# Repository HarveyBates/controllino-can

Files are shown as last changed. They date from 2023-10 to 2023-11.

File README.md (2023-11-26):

# Controllino-CAN
Small PCB that fits onto the header of a [Controllino-MEGA](https://www.controllino.com/product/controllino-mega/) allowing it to interface with CAN devices through SPI. Does not take up any output/input pins!

<p float="left" align="center">
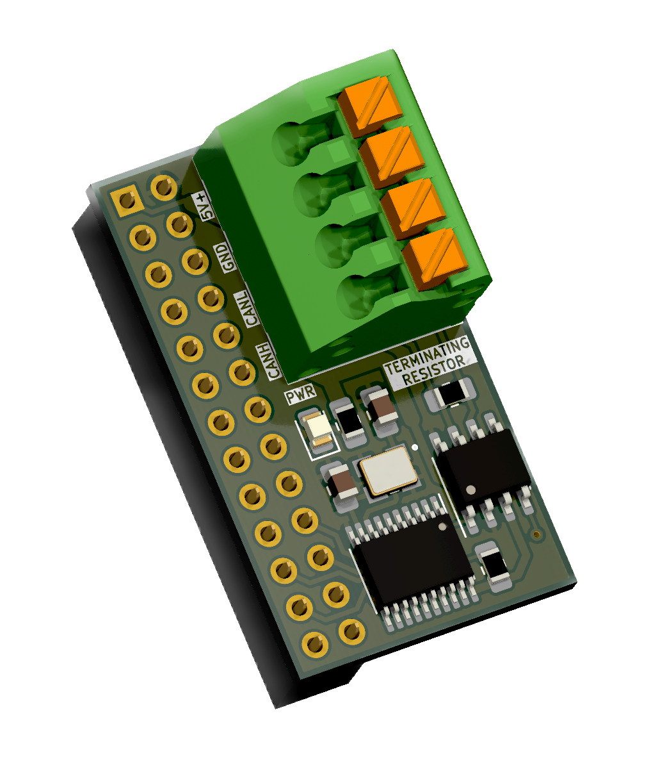
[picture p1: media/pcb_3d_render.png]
   
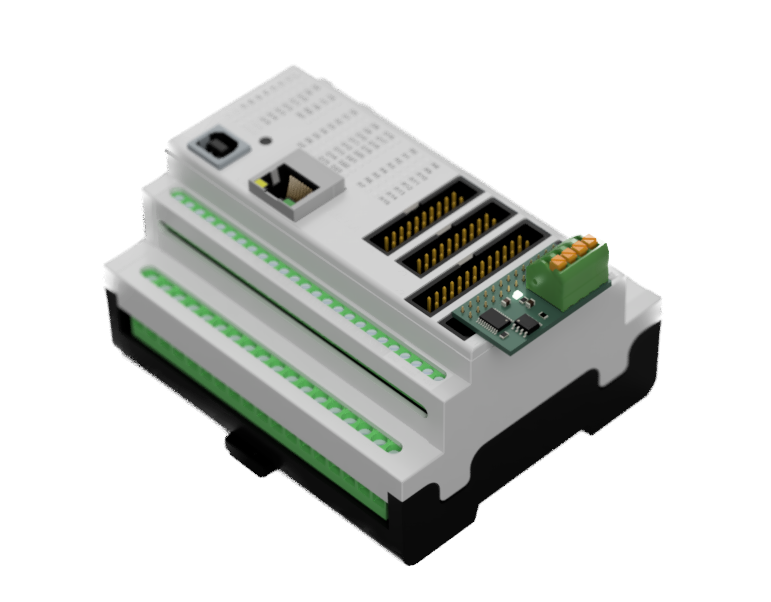
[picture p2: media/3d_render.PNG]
  
</p>

## Example Code
Utilises the [MCP2515 arduino library](https://github.com/autowp/arduino-mcp2515). See futher information in the [examples folder](https://github.com/HarveyBates/controllino-can/tree/main/examples).

```cpp
#include <Controllino.h>
#include "mcp2515.h"

#define BIT_RATE CAN_500KBPS
#define NODE_ID 0x0A // Node-ID = 10
#define FUNCTION_CODE 0x180 // CANopen PDO1_TX

// Setup MCP2515 lib with SPI chip-select pin
MCP2515 can(CONTROLLINO_PIN_HEADER_SS);

void setup() {
  Serial.begin(115200);
  Controllino_RTC_init();
  can.reset();
  can.setBitrate(BIT_RATE, MCP_8MHZ);
  can.setNormalMode();
}

void loop() {
  can_frame frame{};
  frame.can_dlc = 8;
  frame.can_id = FUNCTION_CODE | NODE_ID;
  if (can.sendMessage(&frame) == MCP2515::ERROR_OK) {
    Serial.println("TX");
  } else {
    Serial.println("ERR");
  }
  delay(5000);
}
```

## BOM
The bill-of-materials can be found [here](https://github.com/HarveyBates/controllino-can/blob/main/bom/controllino-can-digikey.csv). **The componets only cost $12 AUD ($8 USD).**

## PCB ordering
Compress the [gerber folder](https://github.com/HarveyBates/controllino-can/tree/main/electronics/gerber) and upload to your PCB manufactuer of choice (e.g. [jlcpcb]([https://jlcpcb.com/](https://cart.jlcpcb.com/quote/)https://cart.jlcpcb.com/quote/) or [PCBway](https://www.pcbway.com/) etc.). As the components are SMD (0805 smallest size) get a stencil (top-side of PCB only) to make assembly easier. **PCB plus stencil is roughly $15 AUD ($10 USD).**

## Licence
Controllino-CAN is licenced under the GNU General Public Licence v3.0 as outlined in the [LICENCE](https://github.com/HarveyBates/controllino-can/blob/main/LICENSE).

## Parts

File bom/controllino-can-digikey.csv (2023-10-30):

Index | Manufacturer Part Number | Manufacturer Name | Description | Availability | Stock Status | Attrition % | Requested Quantity 1 | Pack Quantity 1 | Pack Type 1 | Digi-Key Part Number 1 | Unit Price 1 | Extended Price 1 | Minimum Order Quantity 1 | Customer Reference | Requested Part Number | Lead Weeks | Datasheet | Reference Designator | Part Status
1 | MCP2515T-I/ST | Microchip Technology | IC CAN CONTROLLER W/SPI 20TSSOP | 12,353 | In Stock |  | 1 | 1 | Cut Tape (CT) | MCP2515T-I/STCT-ND | 4.36000 | $4.36 | 1 |  | MCP2515T-I/STCT-ND | 4 | https://ww1.microchip.com/downloads/en/DeviceDoc/MCP2515-Stand-Alone-CAN-Controller-with-SPI-20001801J.pdf |  | Active
2 | C0805C220J5GAC7210 | KEMET | CAP CER 22PF 50V C0G/NP0 0805 | 49,151 | In Stock |  | 2 | 2 | Cut Tape (CT) | 399-C0805C220J5GAC7210CT-ND | 0.16000 | $0.32 | 1 |  | 399-C0805C220J5GAC7210CT-ND | 27 | https://connect.kemet.com:7667/gateway/IntelliData-ComponentDocumentation/1.0/download/datasheet/C0805C220J5GAC7210 |  | Active
3 | LTST-C171GKT | Lite-On Inc. | LED GREEN CLEAR CHIP SMD | 291,266 | In Stock |  | 1 | 1 | Cut Tape (CT) | 160-1423-1-ND | 0.41000 | $0.41 | 1 |  | 160-1423-1-ND | 18 | https://mm.digikey.com/Volume0/opasdata/d220001/medias/docus/1134/LTST-C171GKT.pdf |  | Active
4 | TBL002A-350-04GR-2OR | CUI Devices | TERMINAL BLOCK, SCREWLESS, 3.50, | 128 | In Stock |  | 1 | 1 | Tray | 102-6381-ND | 1.53000 | $1.53 | 1 |  | 102-6381-ND | 11 | https://www.cuidevices.com/product/resource/tbl002a-350.pdf |  | Active
5 | SFH11-PBPC-D13-ST-BK | Sullins Connector Solutions | CONN HDR 26POS 0.1 GOLD PCB | 9,218 | In Stock |  | 1 | 1 | Tray | S9198-ND | 2.27000 | $2.27 | 1 |  | S9198-ND | 11 | https://s3.amazonaws.com/catalogspreads-pdf/PAGE123%20.100%20SFH11%20SERIES%20FEMALE%20HDR%20ST%20RA.pdf |  | Active
6 | RMCF0805FT120R | Stackpole Electronics Inc | RES 120 OHM 1% 1/8W 0805 | 1,033,490 | In Stock |  | 1 | 1 | Cut Tape (CT) | 738-RMCF0805FT120RCT-ND | 0.16000 | $0.16 | 1 |  | 738-RMCF0805FT120RCT-ND | 17 | https://www.seielect.com/catalog/sei-rmcf_rmcp.pdf |  | Active
7 | RC0805JR-0710KL | YAGEO | RES 10K OHM 5% 1/8W 0805 | 1,103,950 | In Stock |  | 1 | 1 | Cut Tape (CT) | 311-10KARCT-ND | 0.16000 | $0.16 | 1 |  | 311-10KARCT-ND | 18 | https://www.yageo.com/upload/media/product/app/datasheet/rchip/pyu-rc_group_51_rohs_l.pdf |  | Active
8 | RK73B2ATTD331J | KOA Speer Electronics, Inc. | RES 330 OHM 5% 1/4W 0805 | 109,215 | In Stock |  | 1 | 1 | Cut Tape (CT) | 2019-RK73B2ATTD331JCT-ND | 0.16000 | $0.16 | 1 |  | 2019-RK73B2ATTD331JCT-ND | 7 | https://www.koaspeer.com/pdfs/RK73B.pdf |  | Active
9 | MCP2562-E/SN | Microchip Technology | IC TRANSCEIVER HALF 1/1 8SOIC | 10,943 | In Stock |  | 1 | 1 | Tube | MCP2562-E/SN-ND | 1.98000 | $1.98 | 1 |  | MCP2562-E/SN-ND | 4 | https://ww1.microchip.com/downloads/en/DeviceDoc/20005167C.pdf |  | Active
10 | ECS-80-12-33-JGN-TR | ECS Inc. | CRYSTAL 8.0000MHZ 12PF SMD | 108,242 | In Stock |  | 1 | 1 | Cut Tape (CT) | 50-ECS-80-12-33-JGN-CT-ND | 1.03000 | $1.03 | 1 |  | 50-ECS-80-12-33-JGN-CT-ND | 13 | https://ecsxtal.com/store/pdf/ecx-32.pdf |  | Active

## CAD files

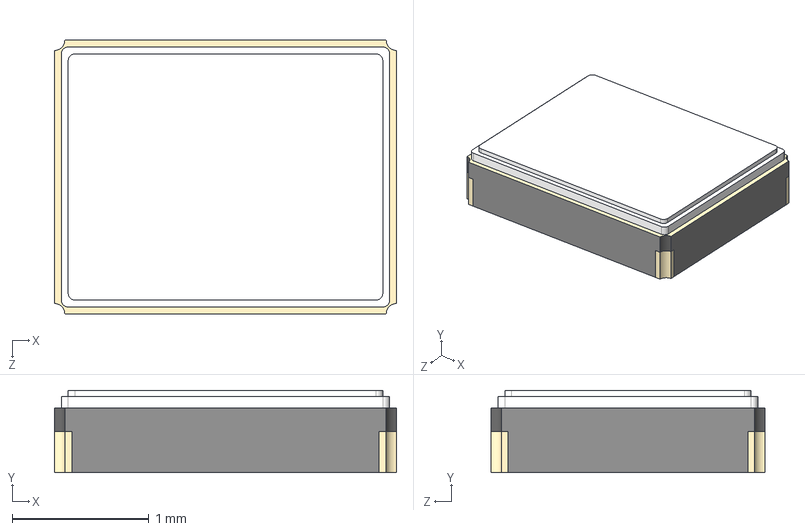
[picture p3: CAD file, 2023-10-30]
electronics/components/extern/3dmodels/crystals/ECS-160-10-36Q-ES-TR.step
2.50 x 0.6 x 2.00 mm

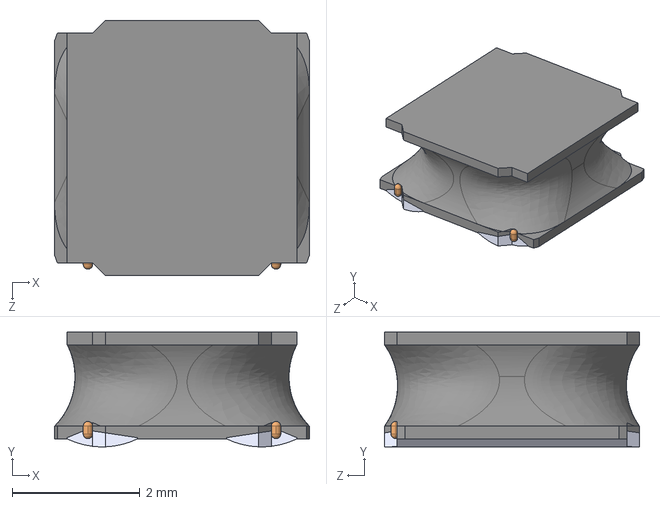
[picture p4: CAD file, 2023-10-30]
electronics/components/extern/3dmodels/inductors/NRS4018T470MDGJ.step
4.00 x 1.80 x 4.00 mm

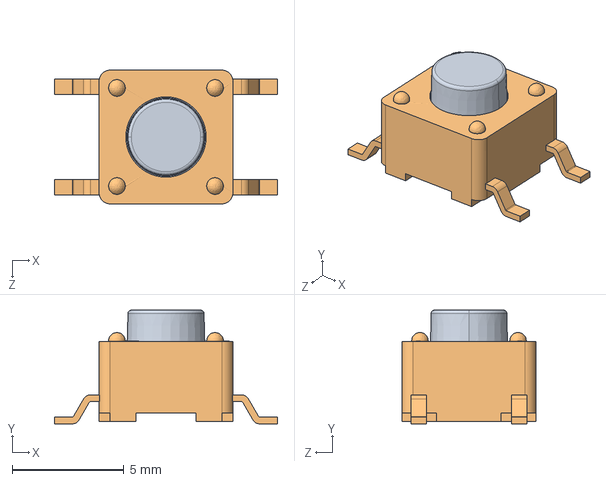
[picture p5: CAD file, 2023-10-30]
electronics/components/extern/3dmodels/tactile_switches/TL3301AF160QG.step
10.0 x 5.10 x 6.00 mm

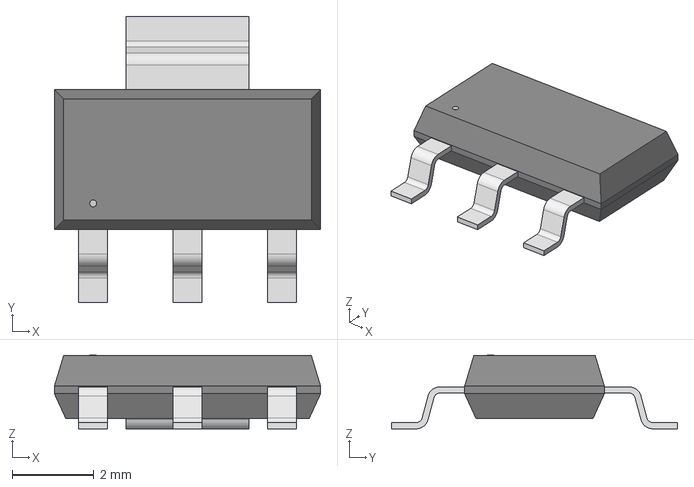
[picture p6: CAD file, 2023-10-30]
electronics/components/extern/3dmodels/voltage_regulator/BD450M2FP3-CE2.step
6.53 x 7.01 x 1.81 mm

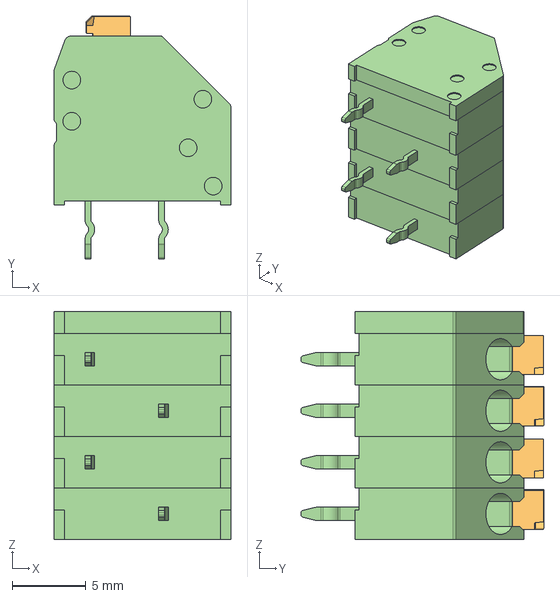
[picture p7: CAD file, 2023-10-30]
electronics/components/extern/3dmodels/wire_to_board/TBL002A-350-04GR-2OR.step
12.0 x 16.5 x 15.5 mm

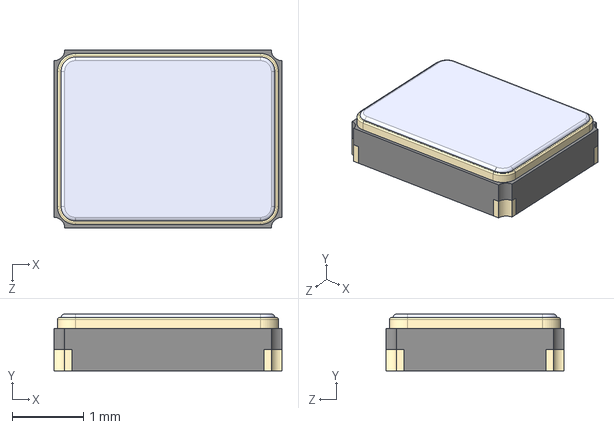
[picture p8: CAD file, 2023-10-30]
electronics/components/extern/tmp/ECS-80-12-33-JGN-TR/ECS-80-12-33-JGN-TR.step
3.20 x 0.8 x 2.50 mm

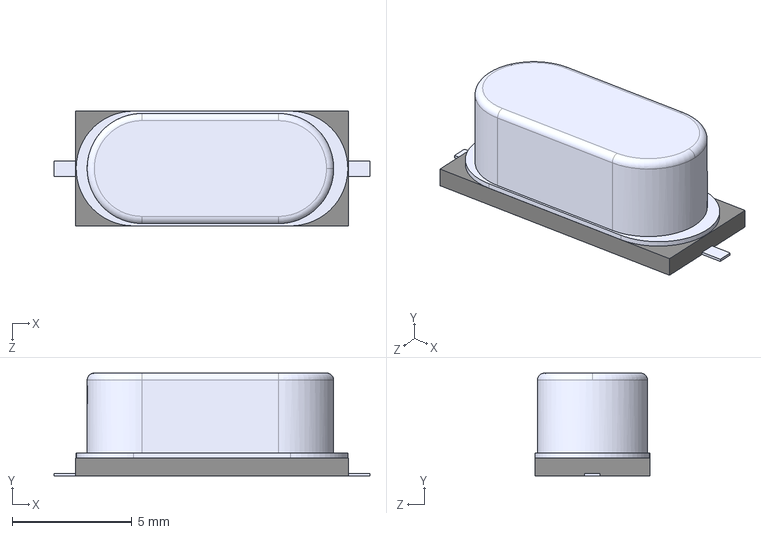
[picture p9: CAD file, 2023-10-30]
electronics/components/extern/tmp/ECS-80-18-5PX-TR/ECS-80-18-5PX-TR.step
13.2 x 4.30 x 4.80 mm

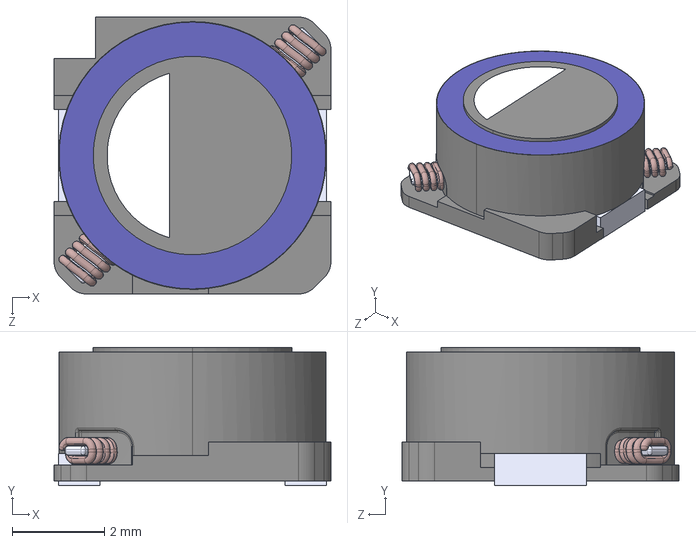
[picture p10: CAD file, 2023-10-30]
electronics/components/extern/tmp/SLF6028T-470MR59-PF/SLF6028T-470MR59-PF.step
6.00 x 3.00 x 6.00 mm

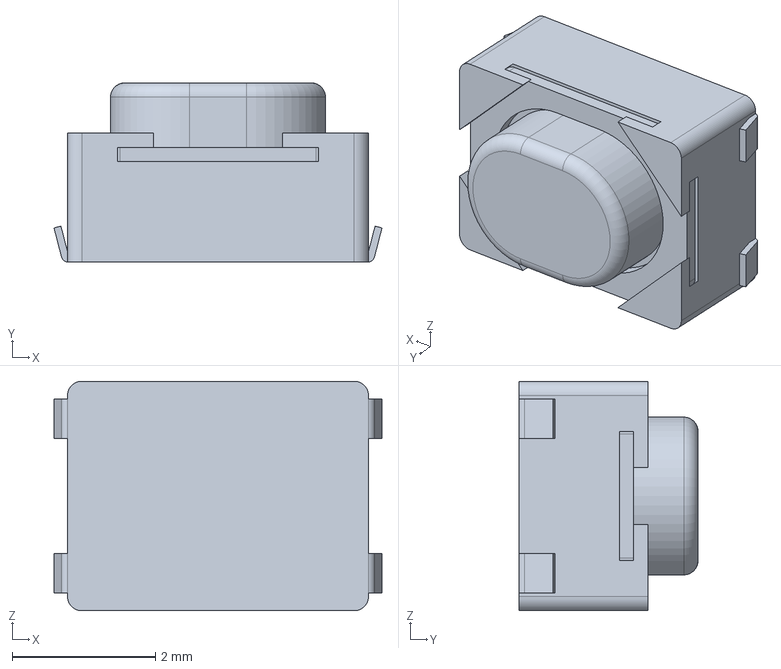
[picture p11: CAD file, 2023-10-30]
electronics/components/extern/3dmodels/tactile_switches/PTS810SJM250SMTRLFS.STEP
4.58 x 2.50 x 3.20 mm

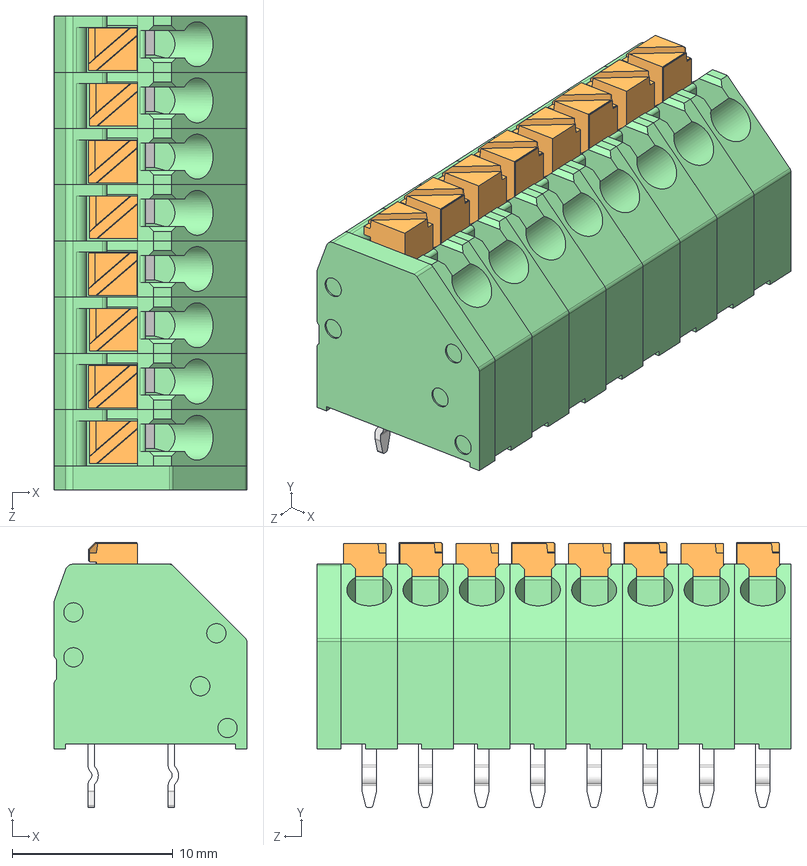
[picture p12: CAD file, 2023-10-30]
electronics/components/extern/3dmodels/wire_to_board/TBL002A-350-08GR-2OR.step
12.0 x 16.5 x 29.5 mm
TBL002A-350 - END CAP_Green
TBL002A-350 - BODY A_Green x 4
TBL002A-350 - BODY B_Green x 4
TBL002A-350 - PUSH BUTTON A_Orange x 4
TBL002A-350 - PUSH BUTTON B_Orange x 4

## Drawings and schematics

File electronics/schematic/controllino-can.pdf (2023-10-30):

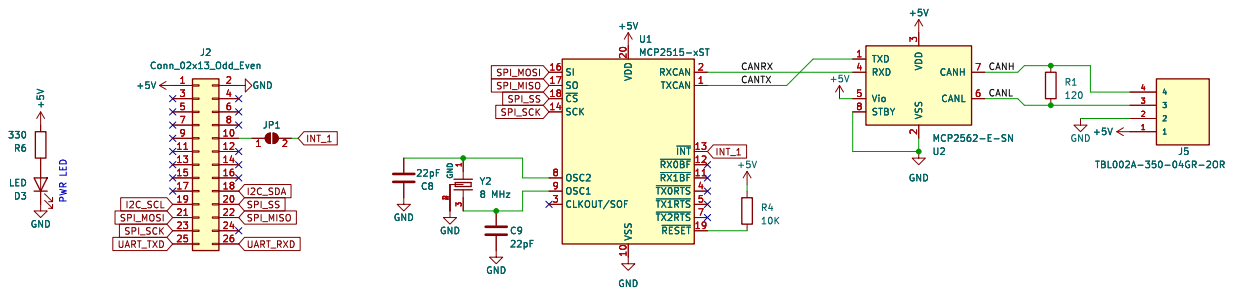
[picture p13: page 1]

3 RXD 4 Vio 5 CANL 6 CANH 7 STBY 8 U1 MCP2515-xST

3 RXD 4 Vio 5 CANL 6 CANH 7 STBY 8 U2 MCP2562-E-SN

Id: 1/1 Title: Controllino-CAN

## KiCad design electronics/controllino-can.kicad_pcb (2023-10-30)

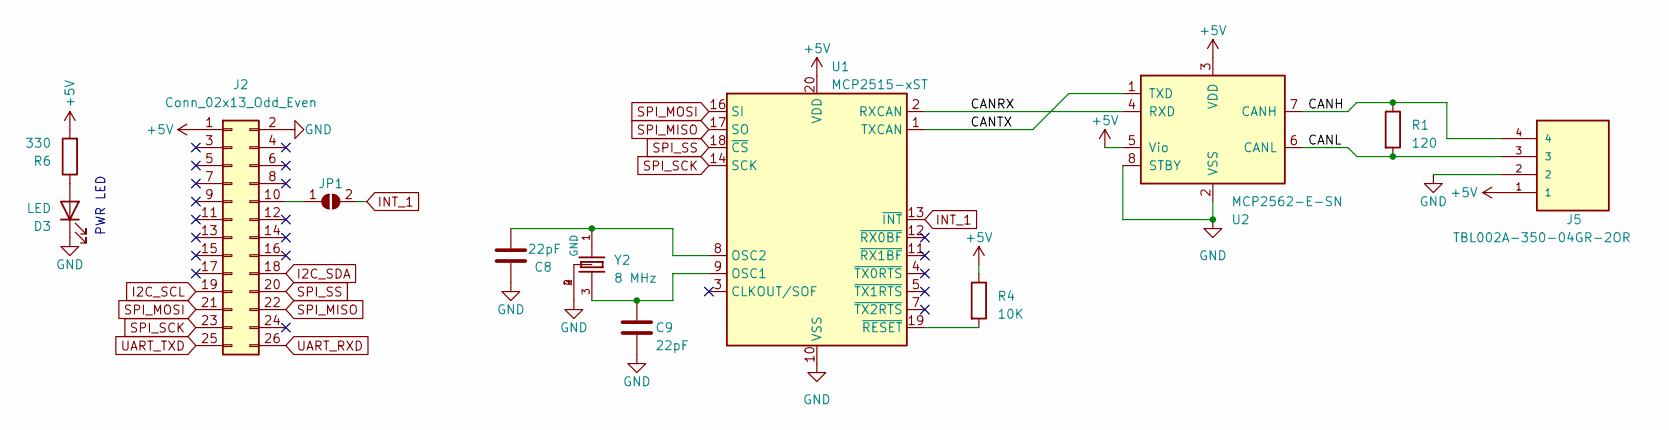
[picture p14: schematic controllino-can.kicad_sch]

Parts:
C8, C9: 22pF; C_0805_2012Metric_Pad1.18x1.45mm_HandSolder
D3: LED; LED_0805_2012Metric
J2: Conn_02x13_Odd_Even; PinSocket_2x13_P2.54mm_Vertical
J5: TBL002A-350-04GR-2OR; PARTREV 1.0
JP1: SolderJumper_2_Open; SolderJumper-2_P1.3mm_Open_Pad1.0x1.5mm
R1: 120; R_0805_2012Metric_Pad1.20x1.40mm_HandSolder
R4: 10K; R_0805_2012Metric_Pad1.20x1.40mm_HandSolder
R6: 330; R_0805_2012Metric_Pad1.20x1.40mm_HandSolder
U1: MCP2515-xST; TSSOP-20_4.4x6.5mm_P0.65mm
U2: MCP2562-E-SN; SOIC-8_3.9x4.9mm_P1.27mm
Y2: 8 MHz; ECS-80-12-33-JGN-TR

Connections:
+5V: J2.1, J5.1, R4.1, R6.2, U1.20 (VDD), U2.3 (VDD), U2.5 (Vio)
/CANH: J5.4, R1.1, U2.7 (CANH)
/CANL: J5.3, R1.2, U2.6 (CANL)
/CANRX: U1.2 (RXCAN), U2.4 (RXD)
/CANTX: U1.1 (TXCAN), U2.1 (TXD)
GND: C8.1, C9.2, D3.1 (K), J2.2, J5.2, U1.10 (VSS), U2.2 (VSS), U2.8 (STBY), Y2.2 (GND), Y2.4
I2C_SCL: J2.19
I2C_SDA: J2.18
INT_1: JP1.2 (B), U1.13 (~INT)
unnamed: D3.2 (A), R6.1
unnamed: J2.10, JP1.1 (A)
unnamed: C9.1, U1.9 (OSC1), Y2.3
unnamed: C8.2, U1.8 (OSC2), Y2.1
unnamed: R4.2, U1.19 (~RESET)
SPI_MISO: J2.22, U1.17 (SO)
SPI_MOSI: J2.21, U1.16 (SI)
SPI_SCK: J2.23, U1.14 (SCK)
SPI_SS: J2.20, U1.18 (~CS)
UART_RXD: J2.26
UART_TXD: J2.25

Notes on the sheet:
PWR LED

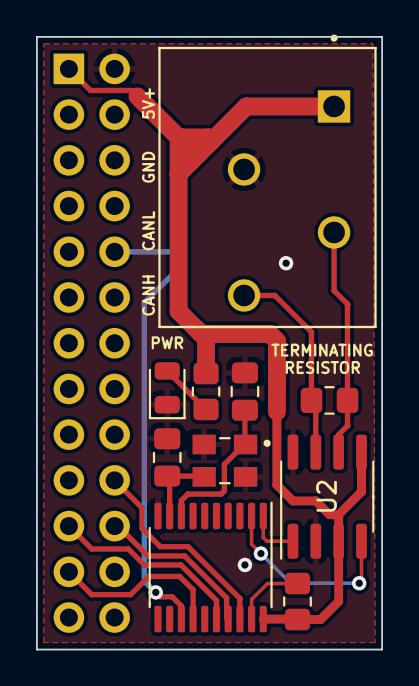
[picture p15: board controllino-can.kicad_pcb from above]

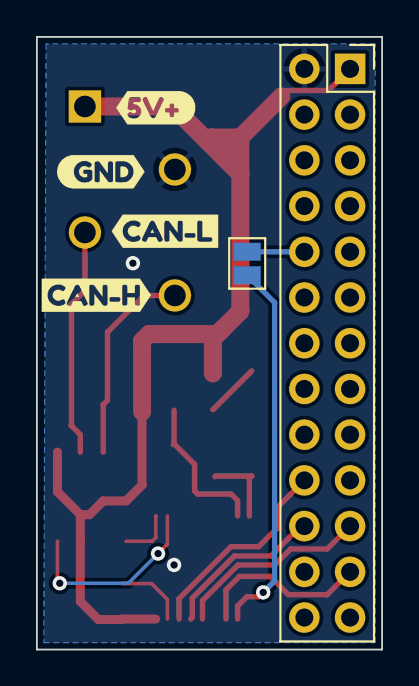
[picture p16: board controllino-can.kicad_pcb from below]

Board: 2 copper layers, 19.2 x 34.0 mm, 16 parts (6 on the bottom side), 16 nets.

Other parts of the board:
kibuzzard-653F042B: G***; kibuzzard-653F042B
kibuzzard-653F047F: G***; kibuzzard-653F047F
kibuzzard-653F0443: G***; kibuzzard-653F0443
kibuzzard-653F0498: G***; kibuzzard-653F0498

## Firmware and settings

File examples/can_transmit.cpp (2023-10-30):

// Controllino defintions
#include <Controllino.h>

// CAN controller lib (https://github.com/autowp/arduino-mcp2515)
#include "mcp2515.h"

// Set bit rate for your CAN bus
#define BIT_RATE CAN_500KBPS

// NODE ID
#define NODE_ID 0x0A // Node-ID = 10

// Function code
#define FUNCTION_CODE 0x180 // CANopen PDO1_TX

// Setup MCP2515 lib with SPI chip-select pin
MCP2515 can(CONTROLLINO_PIN_HEADER_SS);

void setup() {
  Serial.begin(115200);

  // Important! Wont work without this line!
  Controllino_RTC_init();

  // Check if CAN controller is working
  if (can.reset() != MCP2515::ERROR_OK) {
    Serial.println("Reset error");
  }

  // Check and set bitrate
  if (can.setBitrate(BIT_RATE, MCP_8MHZ) != MCP2515::ERROR_OK) {
    Serial.println("Bitrate error");
  }

  // Check if normal mode can be enabled
  if (can.setNormalMode() != MCP2515::ERROR_OK) {
    Serial.println("Mode error");
  }
}

// Send a frame every 5000 ms (5 sec)
void loop() {
  can_frame frame{};
  frame.can_dlc = 8;
  frame.can_id = FUNCTION_CODE | NODE_ID; // Create COB-ID (`can_id`)
  if (can.sendMessage(&frame) == MCP2515::ERROR_OK) {
    Serial.println("TX");
  } else {
    Serial.println("ERR");
  }
  delay(5000);
}

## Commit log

2023-10-30 updated pcb silkscreen and added pcb render. Also added BOM for digikey
    [TBL002A-350-04GR-2OR.step, controllino-can-digikey.csv, controllino-can.kicad_pcb]
2023-10-30 added schematic
    [controllino-can.kicad_sch]
